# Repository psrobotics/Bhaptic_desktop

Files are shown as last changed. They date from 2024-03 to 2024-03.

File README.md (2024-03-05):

# Bhaptic_desktop

Bhaptic_desktop is a open-sorce, low-cost 3DOF desktop haptic device like [PHAToM haptic device](https://alliance.seas.upenn.edu/~medesign/wiki/uploads/Courses/Massie94-DSC-Phantom.pdf). It allows user to interact with the virtual while feeling the feedback force. It's an old project back in 2019.

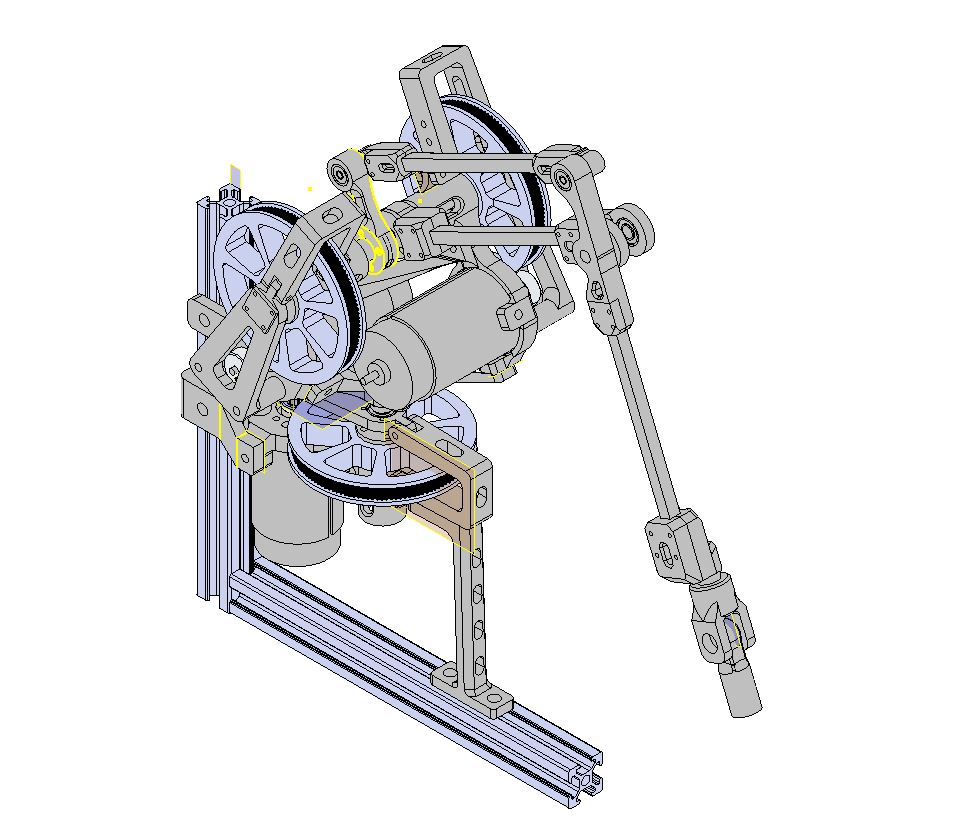
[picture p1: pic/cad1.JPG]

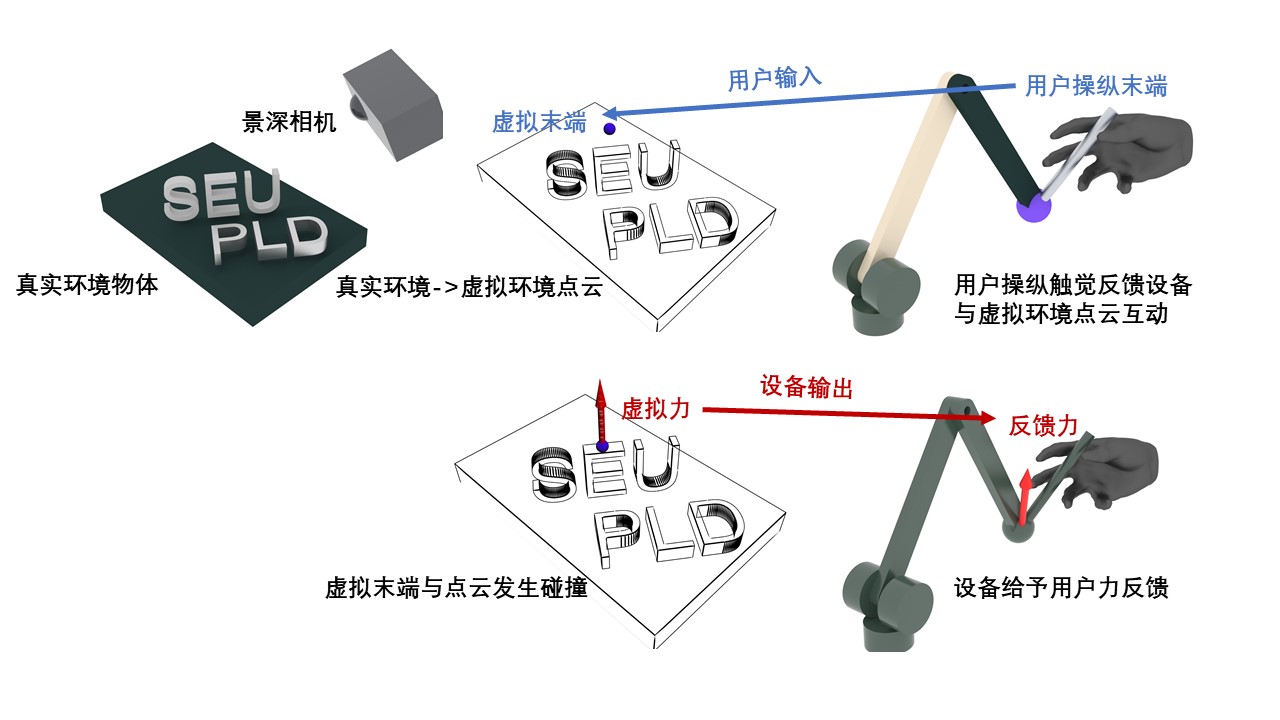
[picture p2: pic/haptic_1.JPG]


## Videos

Bhaptic action 3

## File Structure

* /hardware - CAD, STL exports, CAM file

* /electronic - Motor driver, Encoder reader

* /software - Arduino Firmware, PCL interface

## Pics

### [Motor](https://product.minebeamitsumi.com/en/product/category/rotary/brushmotor/dc/parts/M36N5E.html)


### Controller


### Docu
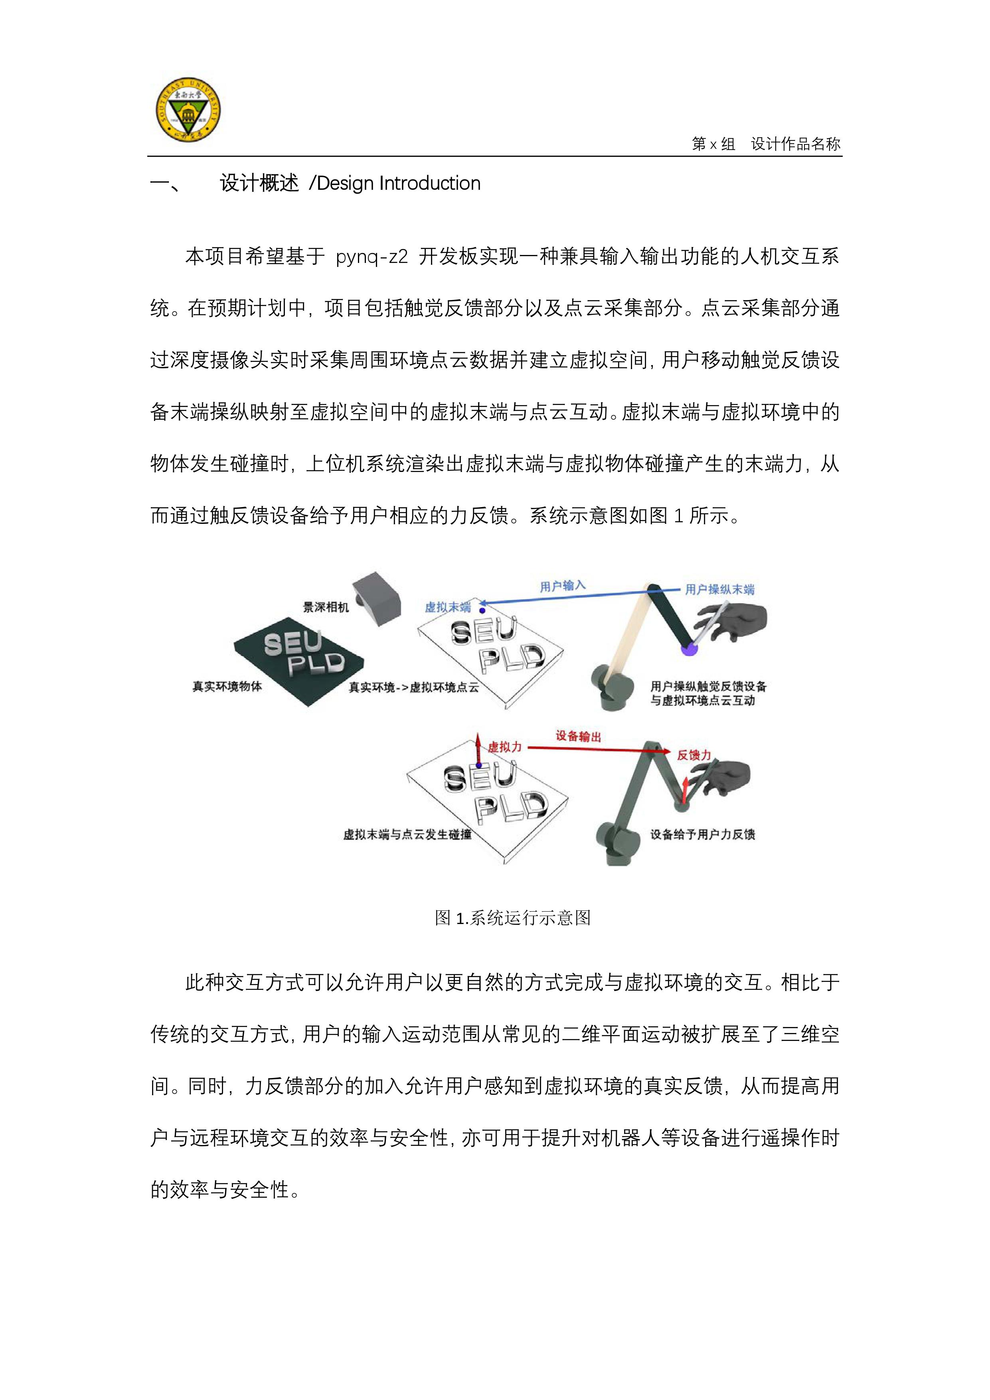
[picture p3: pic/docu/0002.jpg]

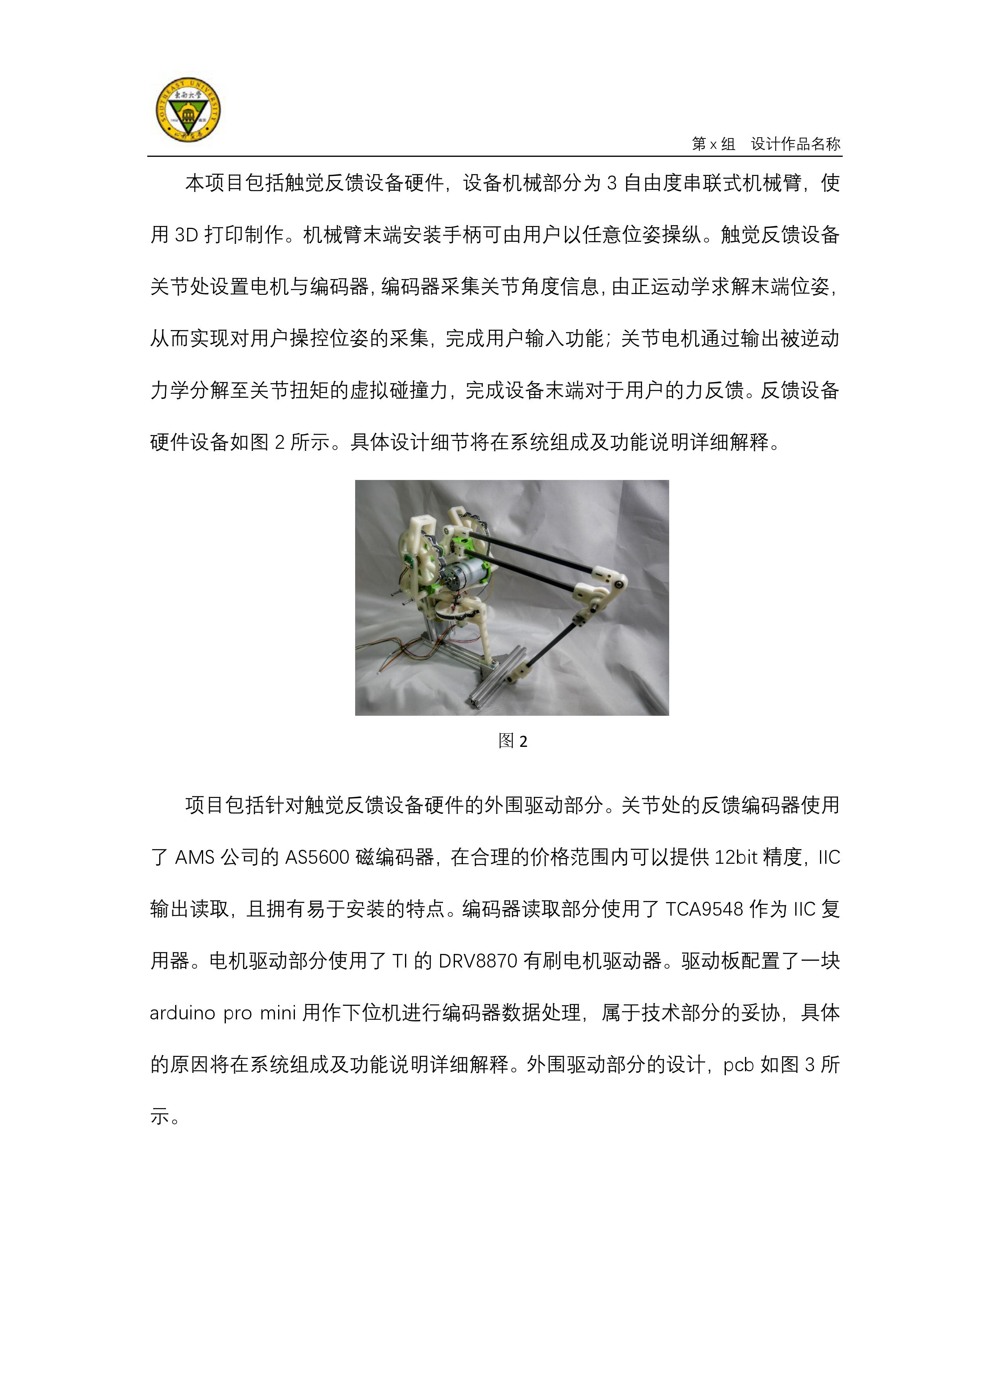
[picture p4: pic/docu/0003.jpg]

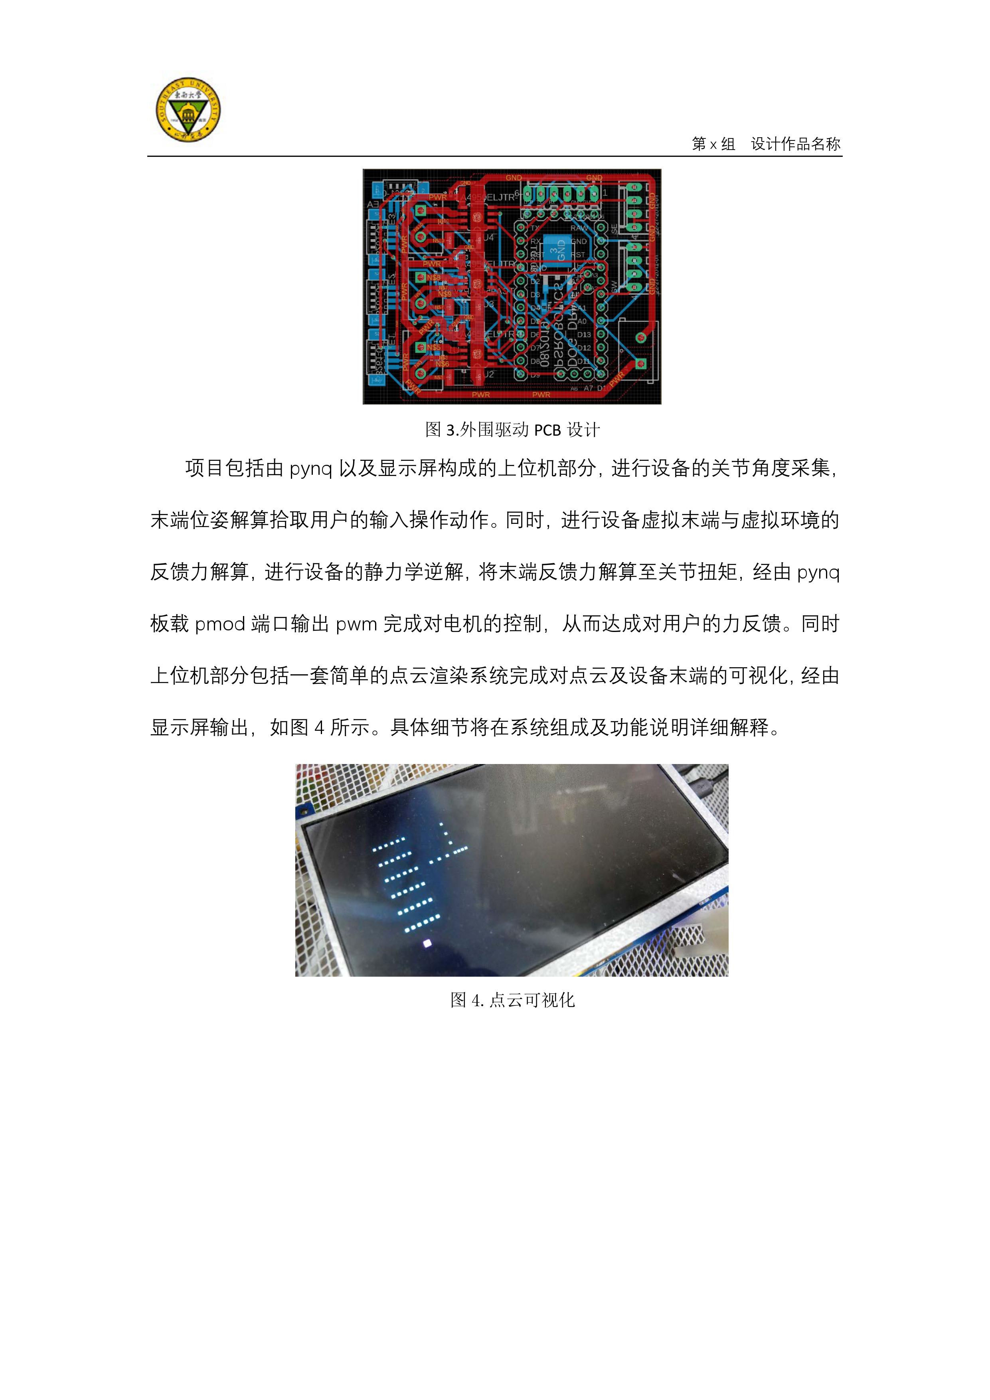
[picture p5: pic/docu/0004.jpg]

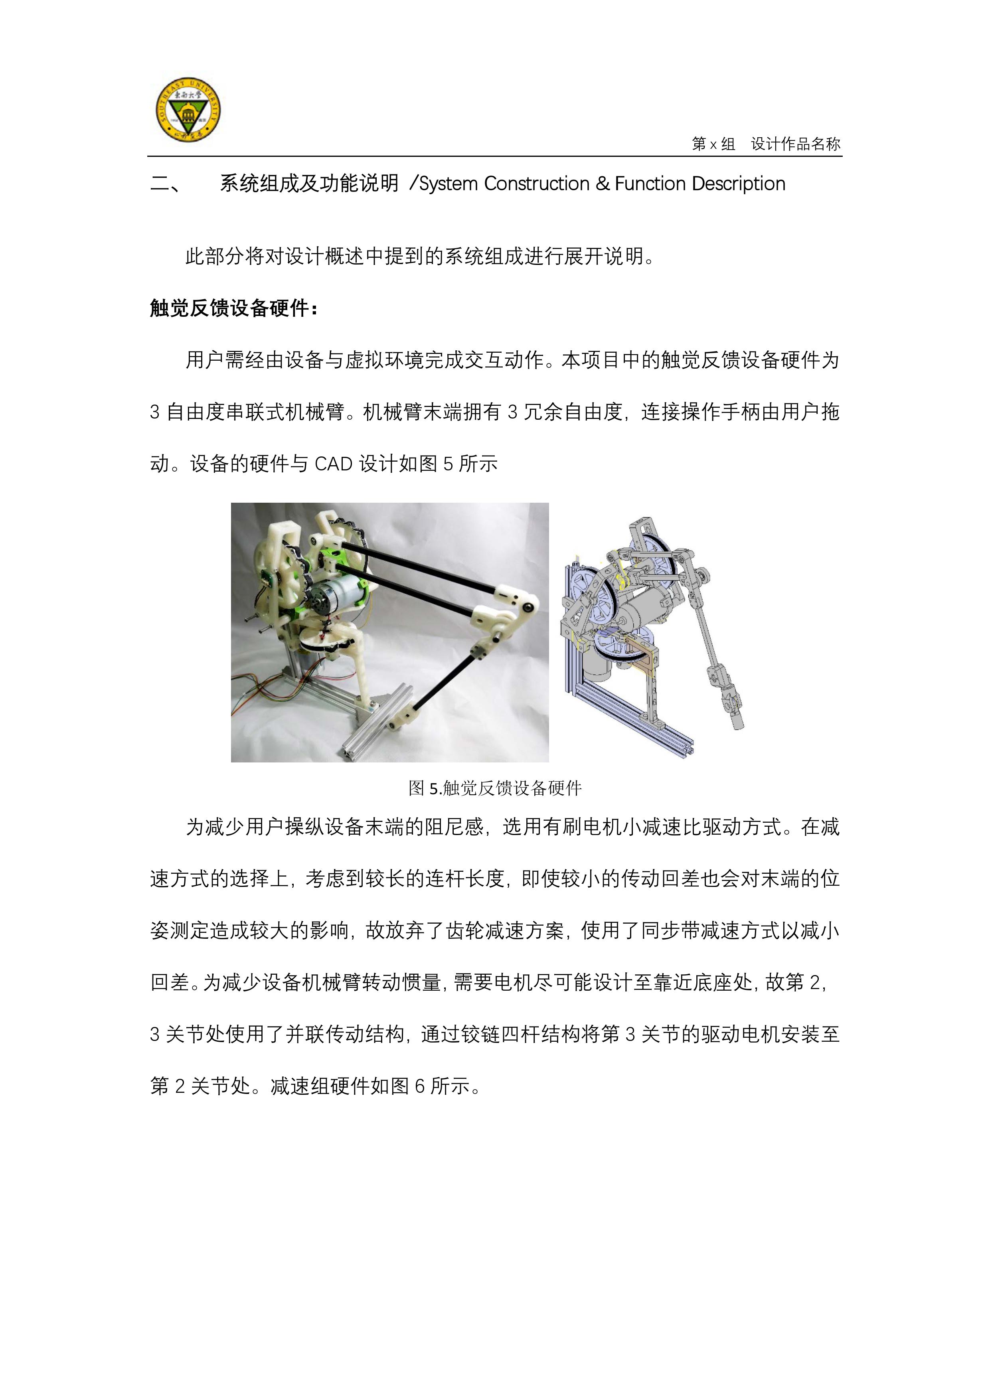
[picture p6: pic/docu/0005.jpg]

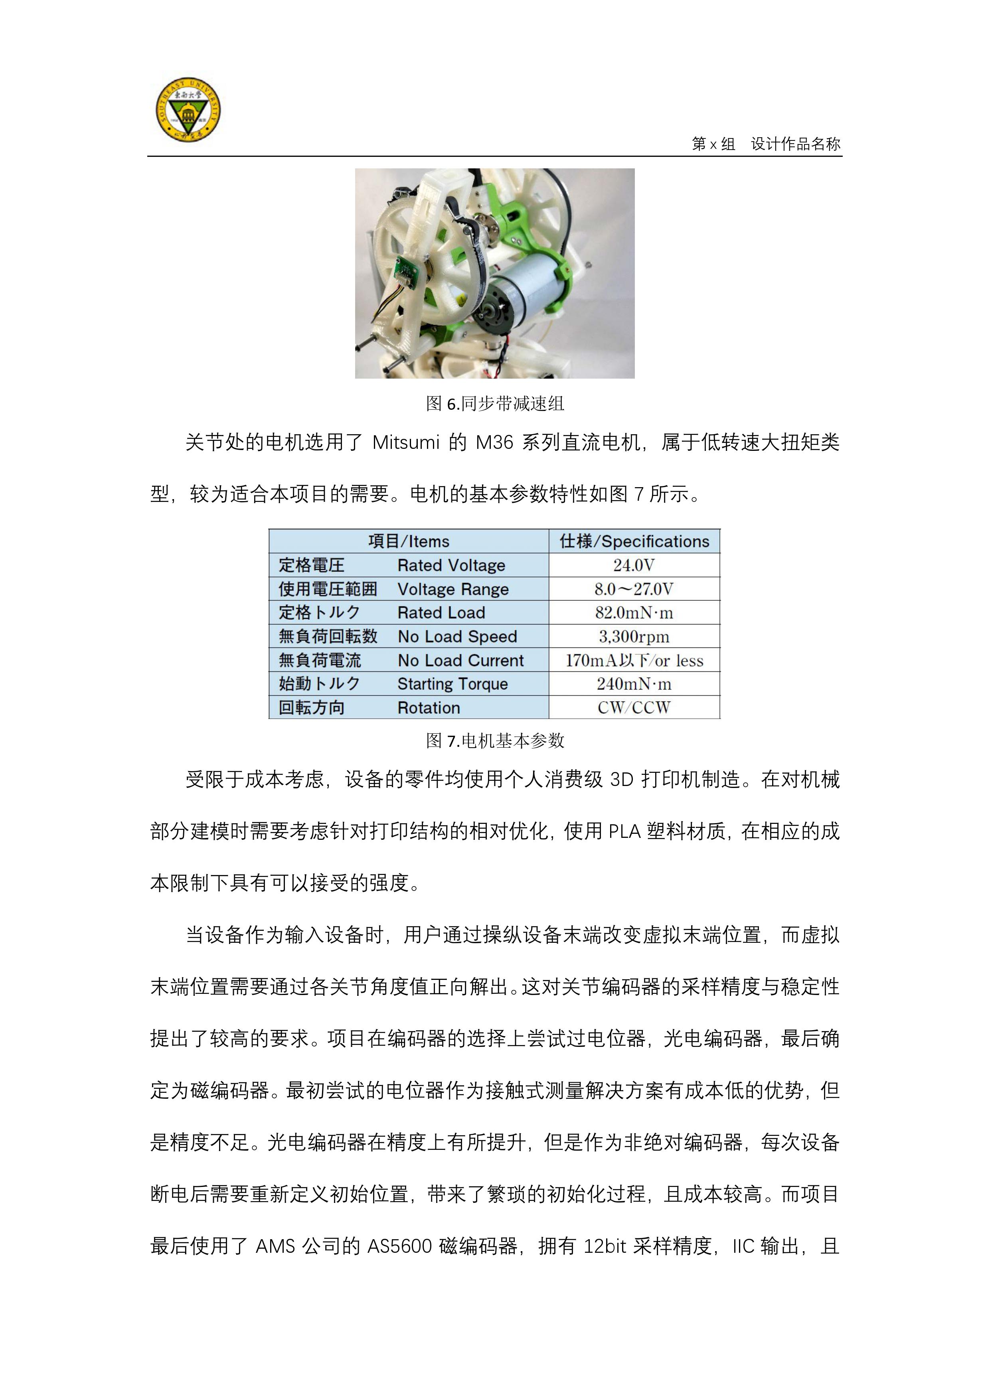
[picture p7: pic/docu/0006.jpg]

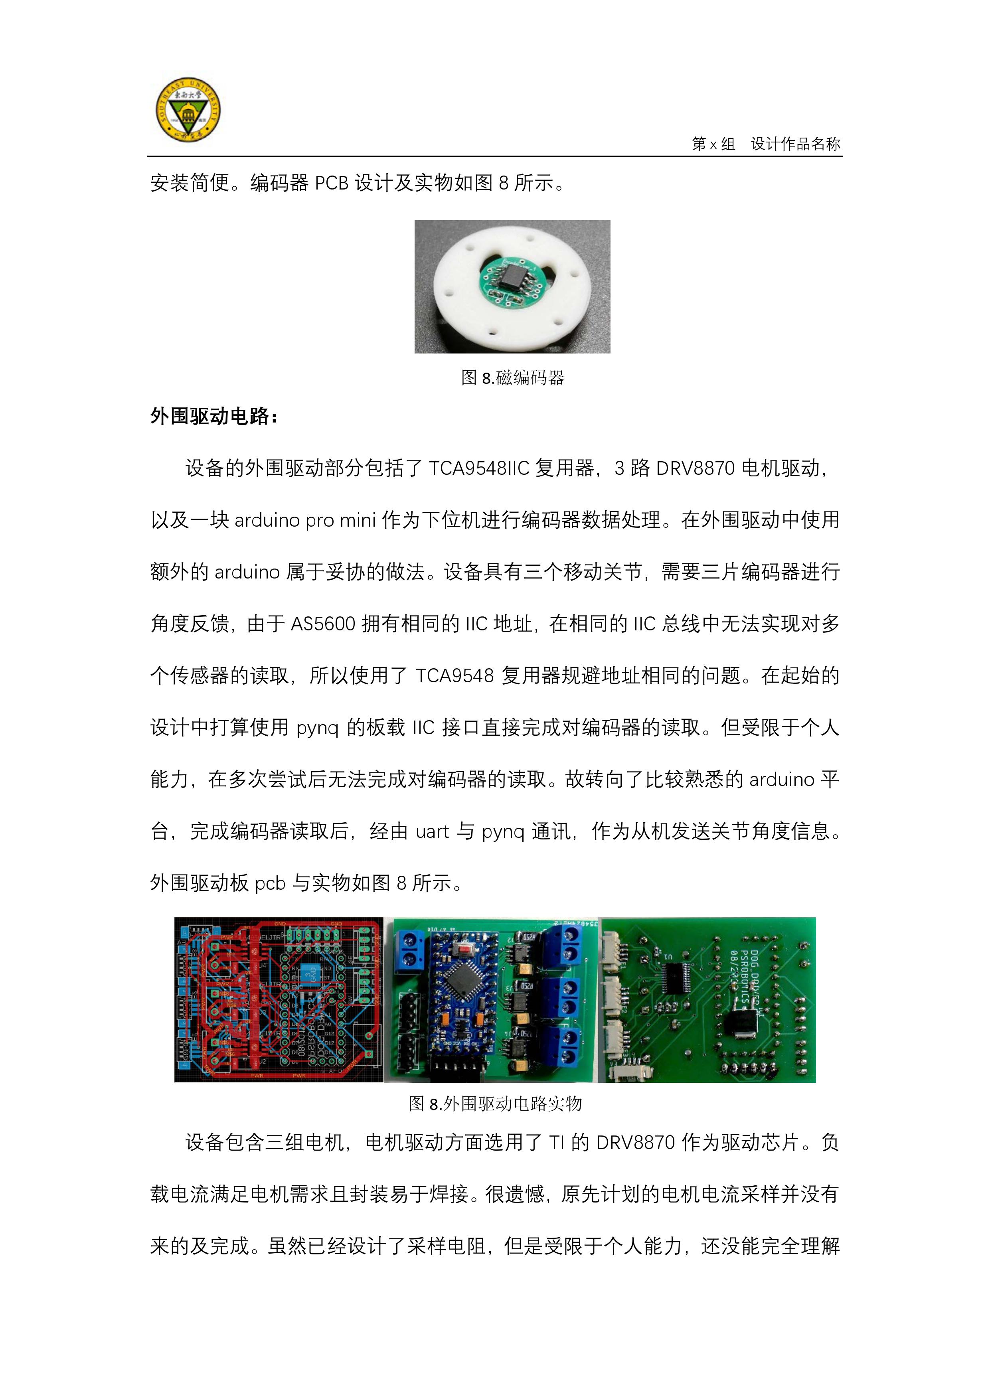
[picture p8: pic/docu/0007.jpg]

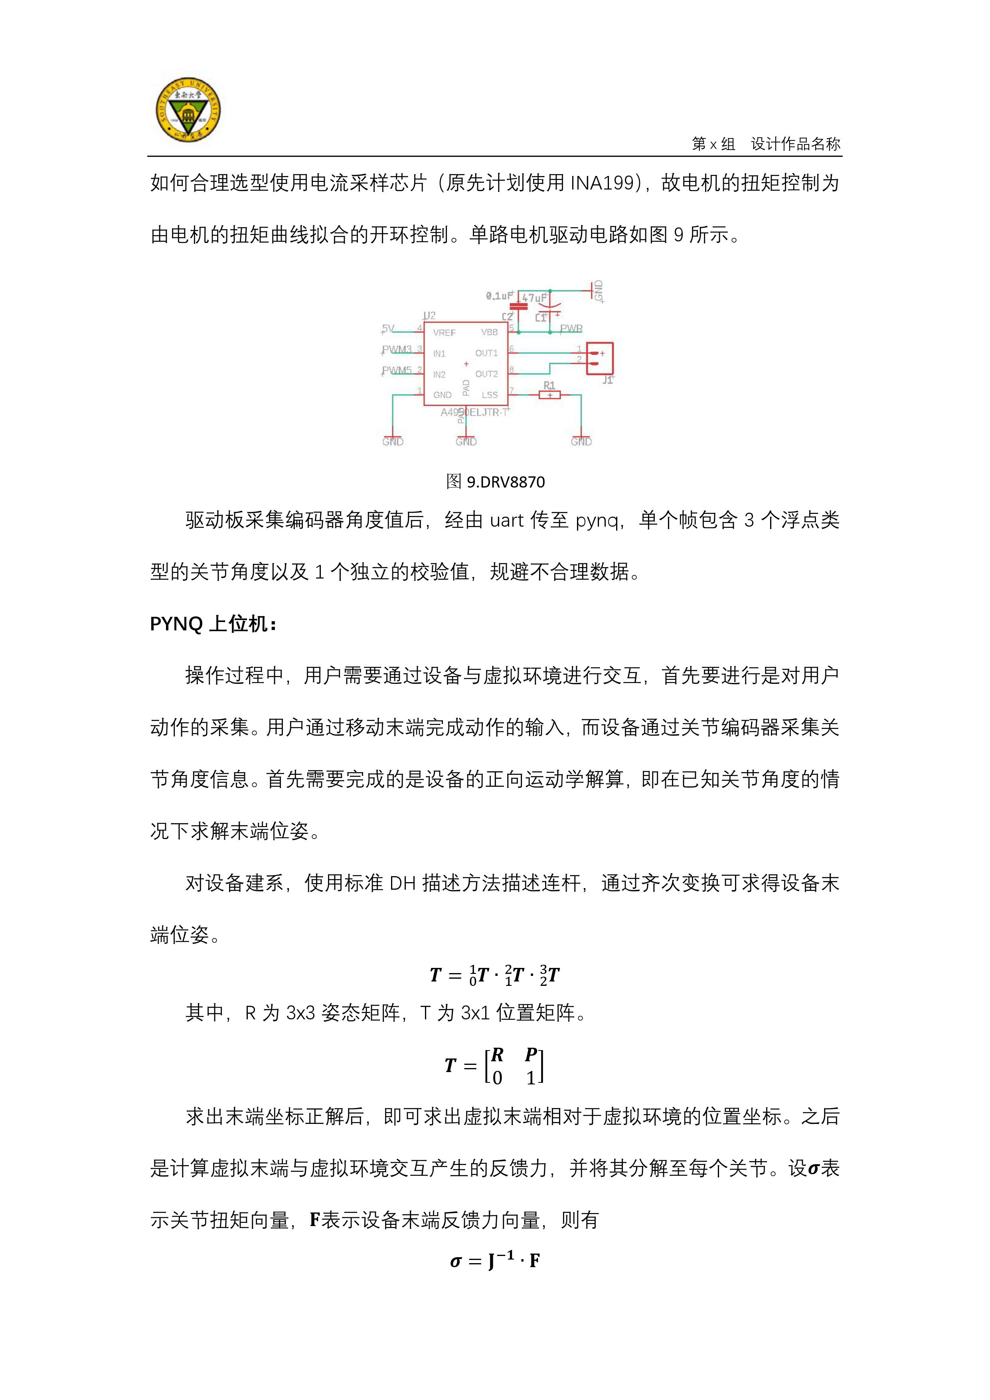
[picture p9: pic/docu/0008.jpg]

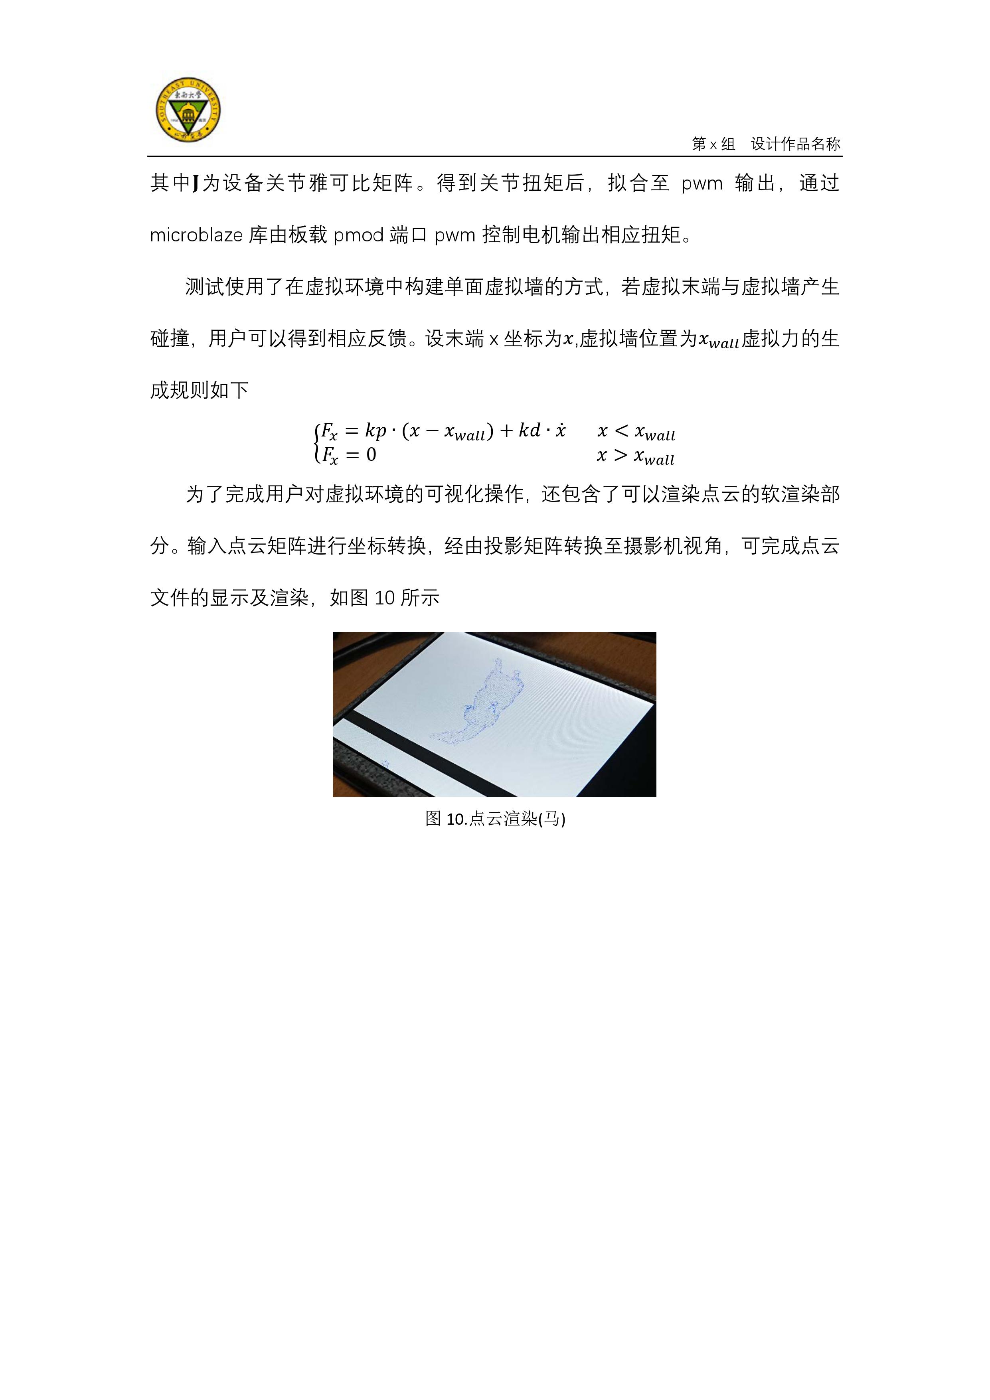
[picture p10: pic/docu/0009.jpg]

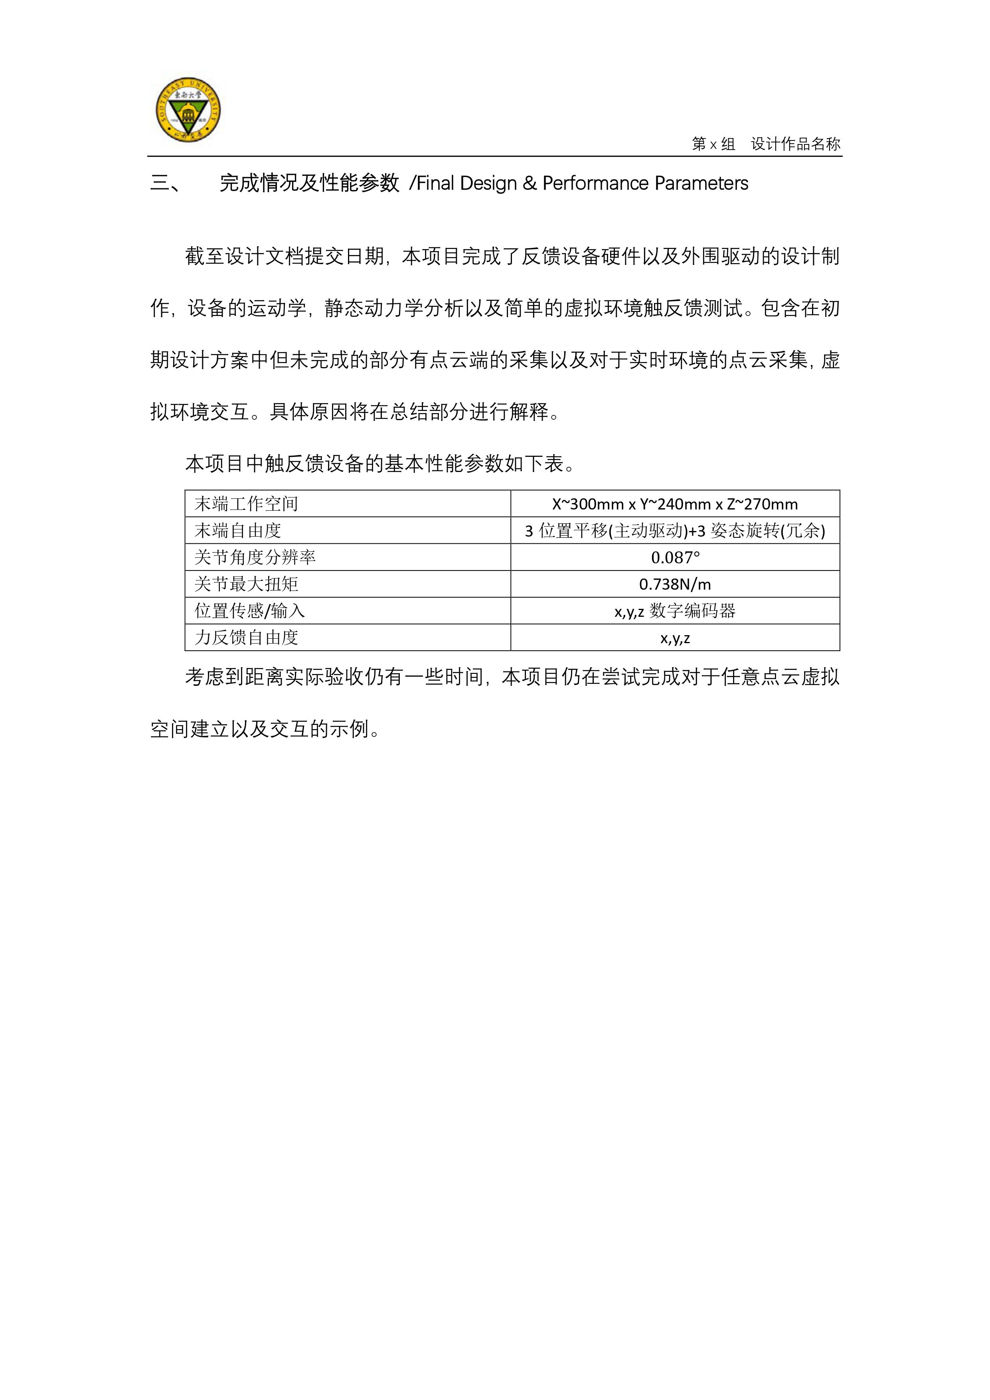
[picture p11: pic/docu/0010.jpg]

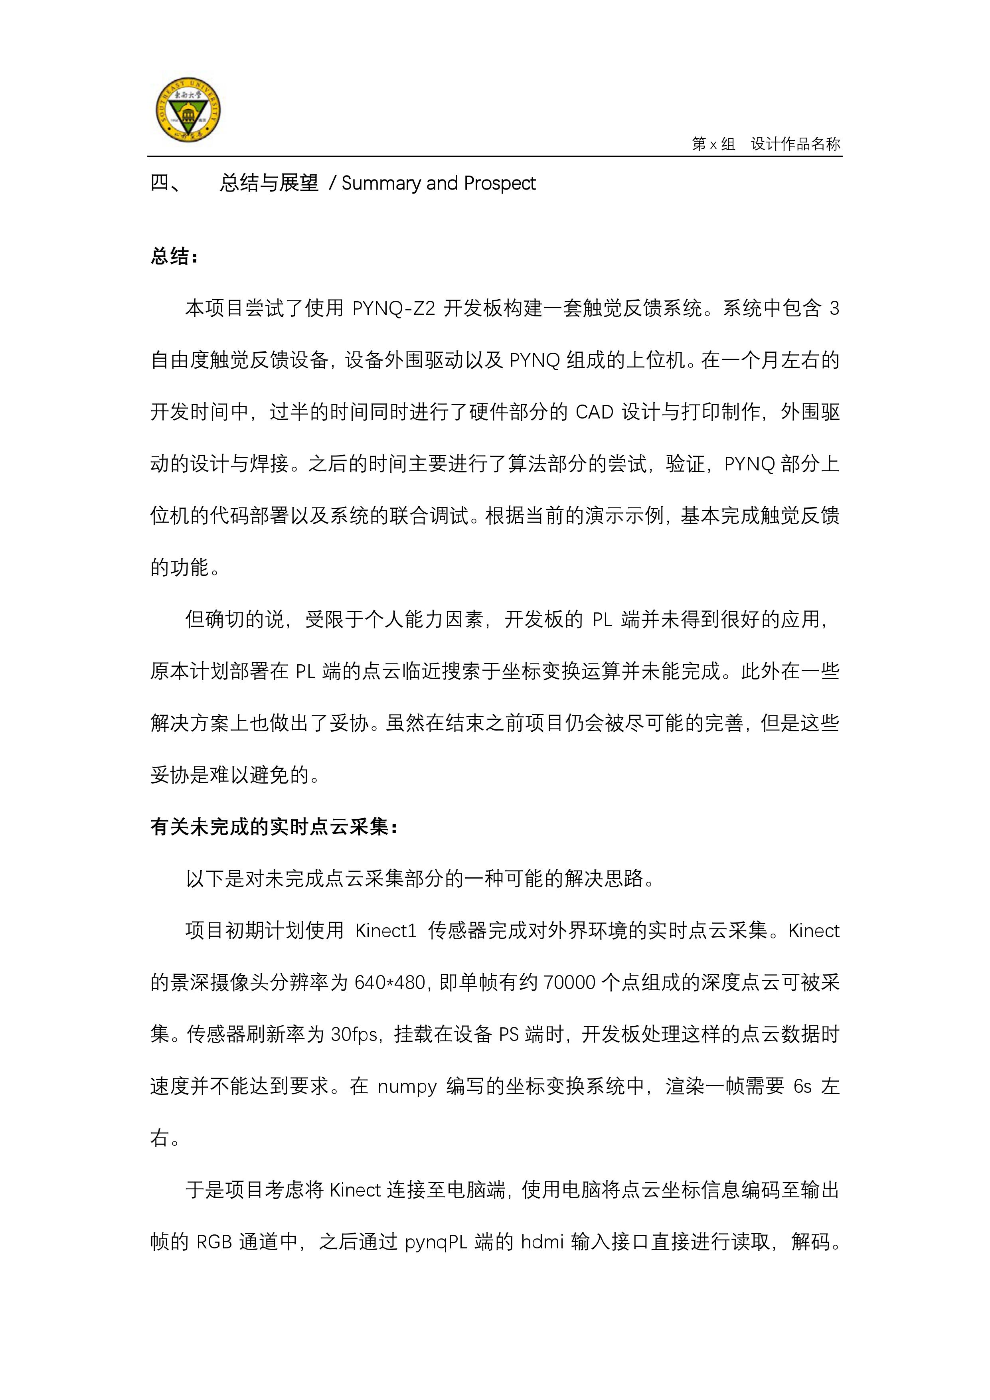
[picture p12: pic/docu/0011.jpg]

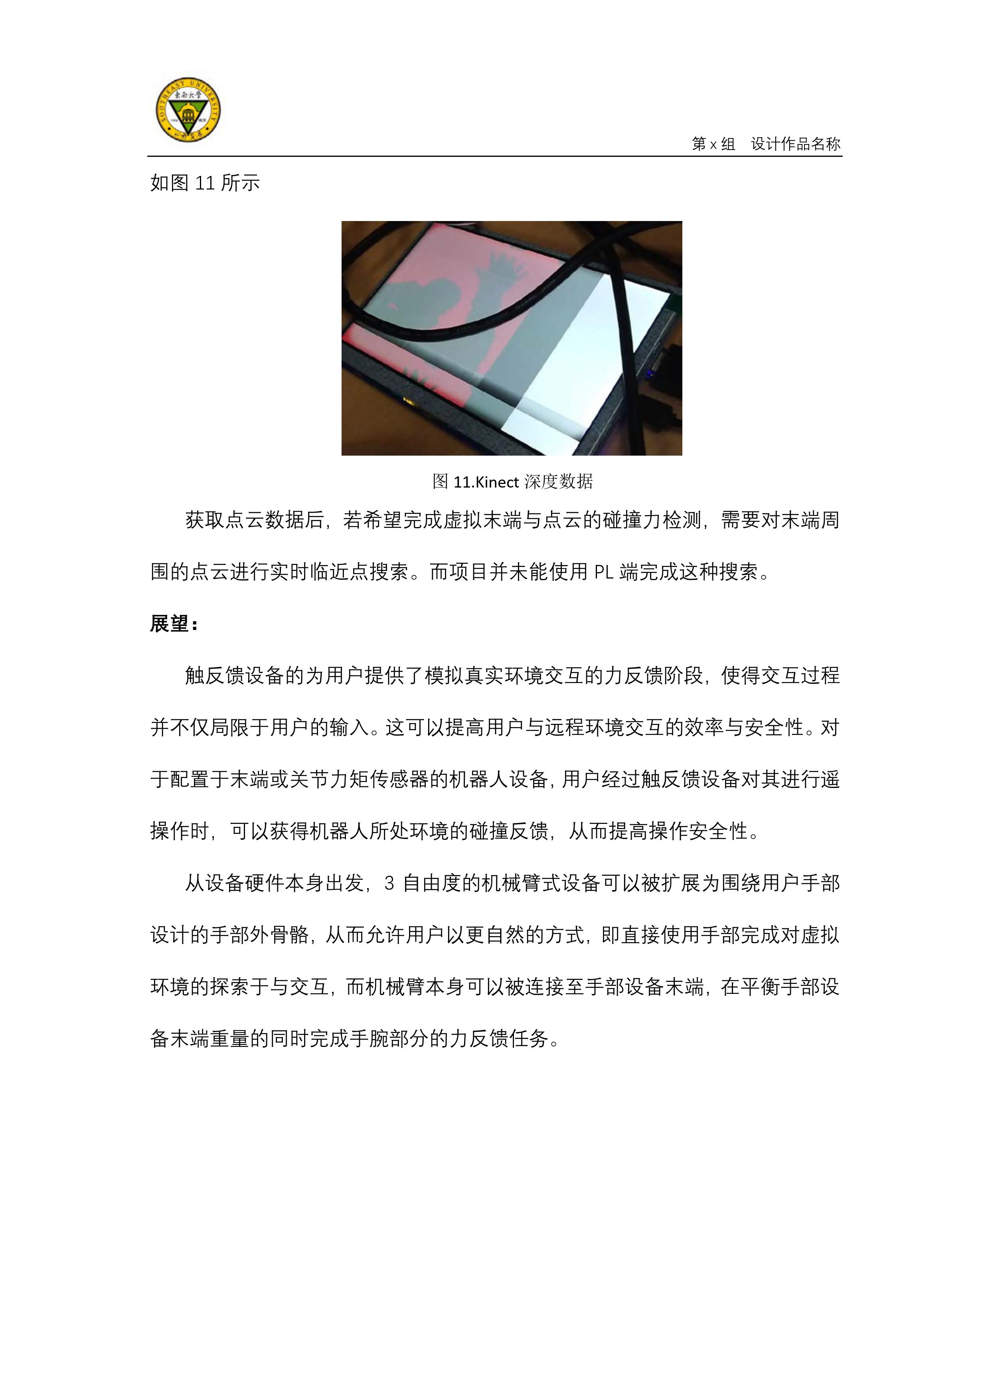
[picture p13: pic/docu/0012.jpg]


## License
MIT License

## Contact
* Shuang Peng, {shuangpe}@usc.edu

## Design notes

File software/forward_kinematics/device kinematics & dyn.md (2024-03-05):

# forward kinematics

```
result_mat_t = 
```



# jacobian matrix

```
J = 
```



```
J_1 = 
```



```
end_torque = 
```



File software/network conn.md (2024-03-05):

# network conn

first thing to do once startup:

sudo ifconfig eth0:1 192.168.2.99 netmask 255.255.255.0

sudo ifconfig eth0 192.168.137.19 netmask 255.255.255.0

```
export GIT_SSL_NO_VERIFY=1
```

sudo ./RedistMaker.Arm

 cp /home/xilinx/kinect/libfreenect/wrappers/python/freenect.c /home/xilinx/pynq/lib

 cp /home/xilinx/kinect/libfreenect/wrappers/python/frame_convert.py /home/xilinx/pynq/lib

 cp /home/xilinx/kinect/libfreenect/wrappers/python/frame_convert.py /home/xilinx/pynq/lib

 cp -r /home/xilinx/pwm_ar.ipynb /home/xilinx/jupyter_notebooks/pwm_test

 cp  -r /home/xilinx/kinect/libfreenect/wrappers/python /opt/python3.6/lib/python3.6/site-packages

sudo cp -r /home/xilinx/xyz/axis.xyz /home/xilinx/jupyter_notebooks/haptic_device_test

 cp  -r /home/xilinx/kinect/libfreenect/wrappers/python/freenect.c /opt/python3.6/lib/python3.6/site-packages

 cp  -r /home/xilinx/kinect/libfreenect/wrappers/python/freenect.pyx /opt/python3.6/lib/python3.6/site-packages

 cp  -r /home/xilinx/kinect/pykinect-python3.6/pykinect /opt/python3.6/lib/python3.6/site-packages

copy to the file lib file, otherwise unable to open

sudo apt-get install python3-pip

 cp /usr/local/lib/python2.7/dist-packages/freenect-0.0.0.egg-info /usr/local/lib/python3.5/dist-packages

 cp /usr/local/lib/python2.7/dist-packages/freenect.so /usr/local/lib/python3.5/dist-packages

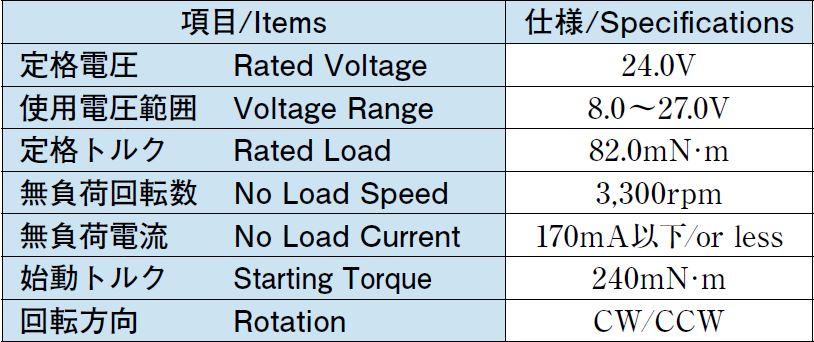
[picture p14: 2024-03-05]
pic/motor_spec.JPG

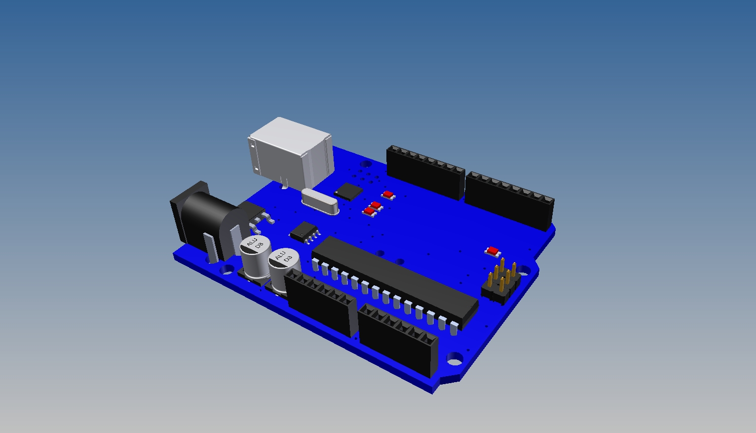
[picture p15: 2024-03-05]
hardware/arduino-uno.snapshot.3/Renderings/arduino uno.jpg

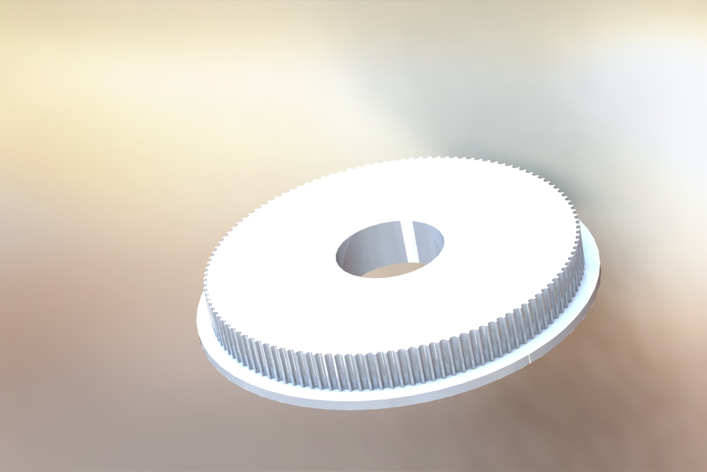
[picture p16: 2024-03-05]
hardware/gt2-pulley-120-tooth-1.snapshot.1/120teeth gt2 pulley picture.JPG

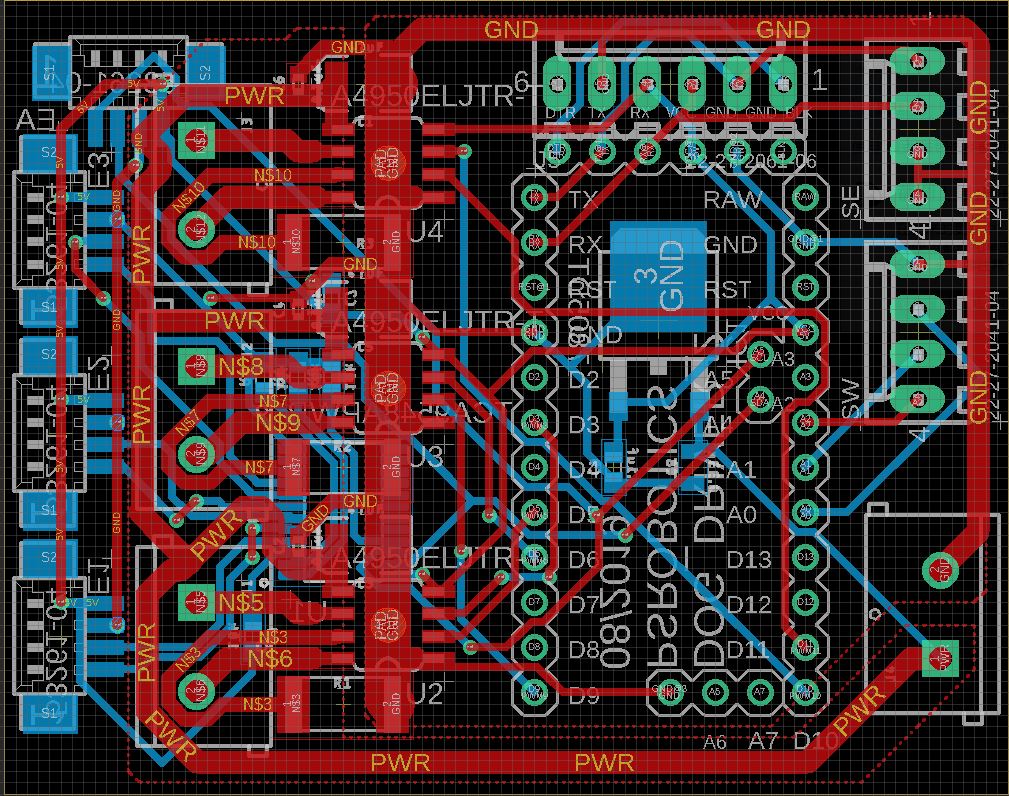
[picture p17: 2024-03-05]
pic/ele_pcb.jpg

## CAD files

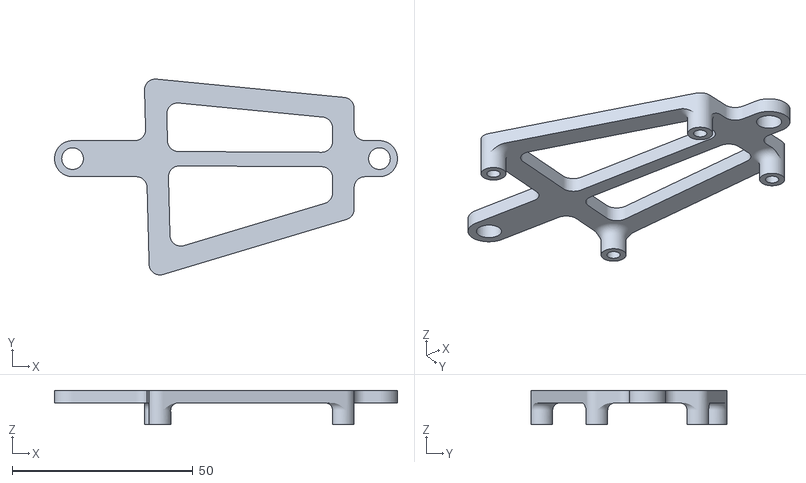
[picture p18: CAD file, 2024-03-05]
hardware/arduino-uno.snapshot.3/uno_holder.stl
95.0 x 54.3 x 9.50

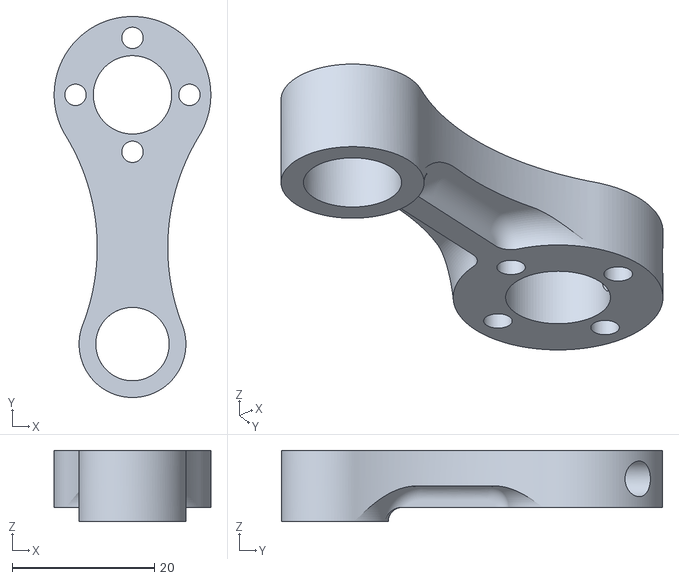
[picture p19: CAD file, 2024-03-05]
hardware/export_20190921/arm_linkage_1_mod.stl
22.0 x 53.5 x 10.0

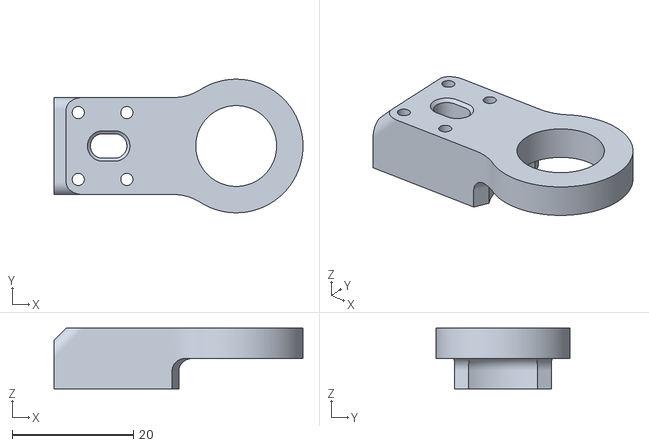
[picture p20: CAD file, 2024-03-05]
hardware/export_20191015/armtip_3.stl
41.0 x 22.0 x 10.0

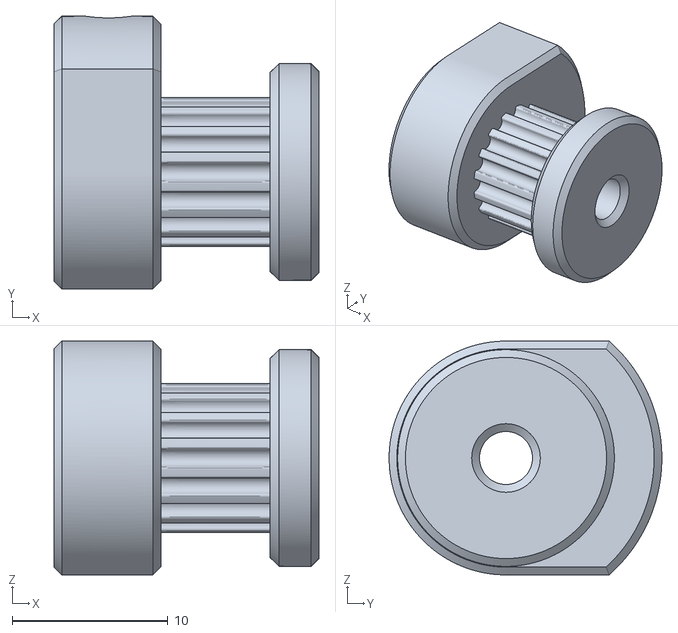
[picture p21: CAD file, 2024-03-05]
hardware/export_20191016/GT2_16T_mod.stl
17.0 x 17.5 x 15.0

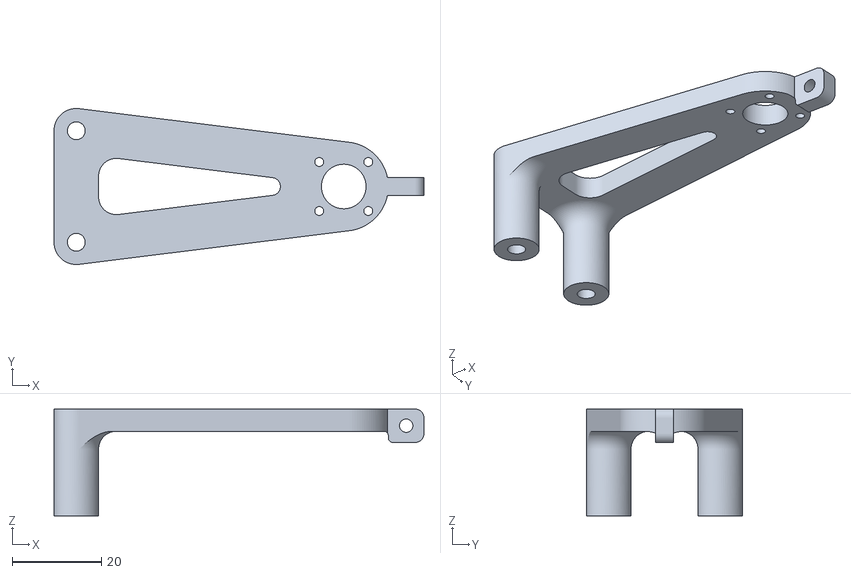
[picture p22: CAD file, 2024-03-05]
hardware/export_20191017/sensor_holder_1_mod.stl
83.0 x 35.0 x 24.0

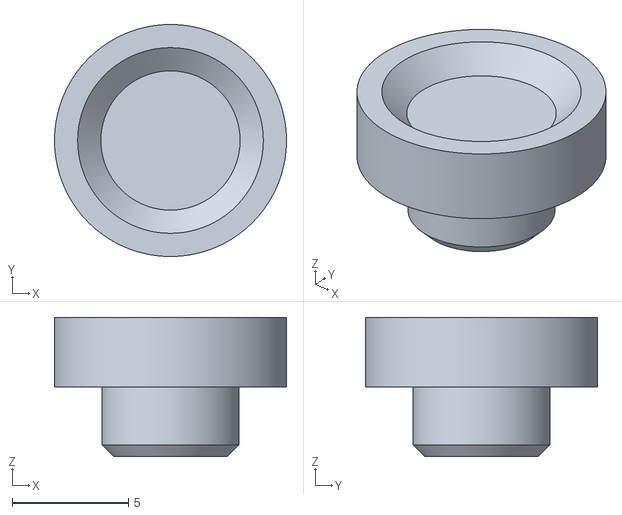
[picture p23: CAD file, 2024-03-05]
hardware/export_20191018/encoder_ma_holder.stl
10.0 x 10.0 x 6.00

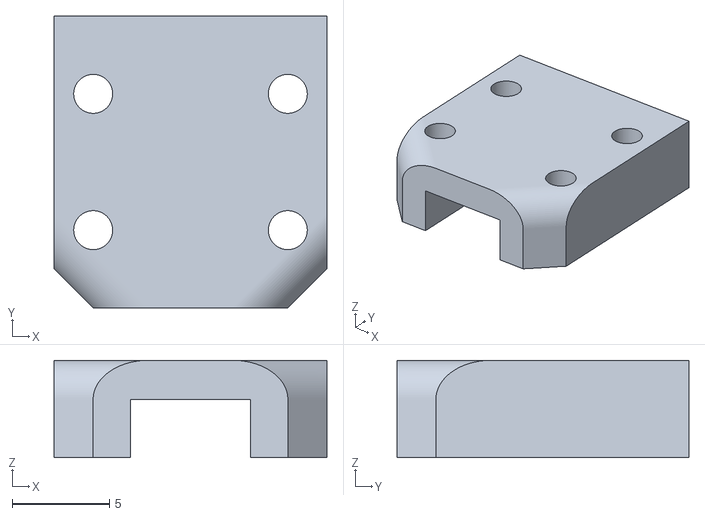
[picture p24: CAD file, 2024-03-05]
hardware/export_20191022/sub_arm_2_mod.stl
14.0 x 15.0 x 5.00

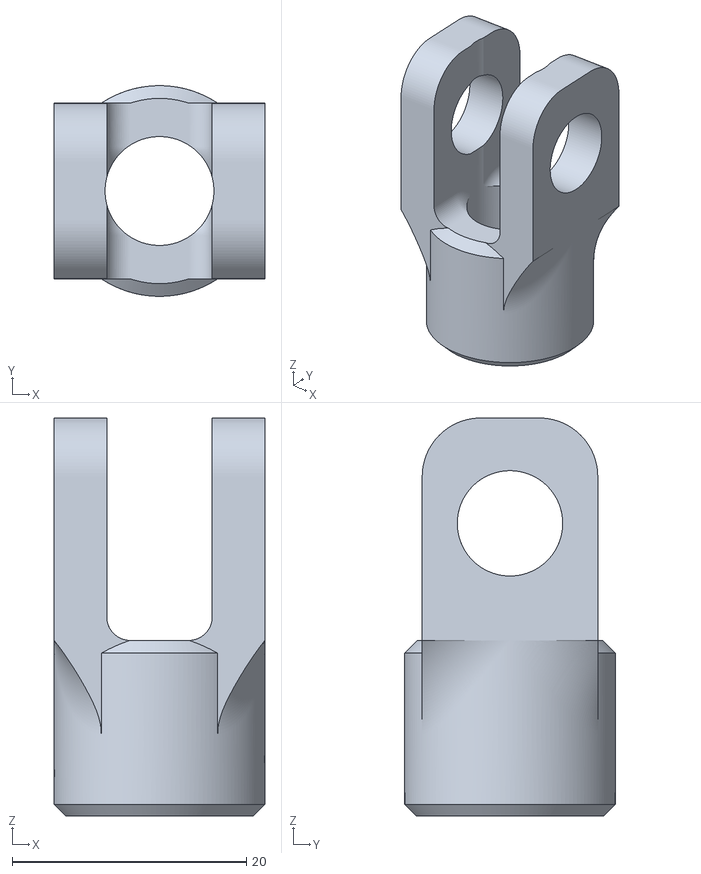
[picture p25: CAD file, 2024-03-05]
hardware/export_20191028/arm_tip_3.stl
18.0 x 18.0 x 34.0

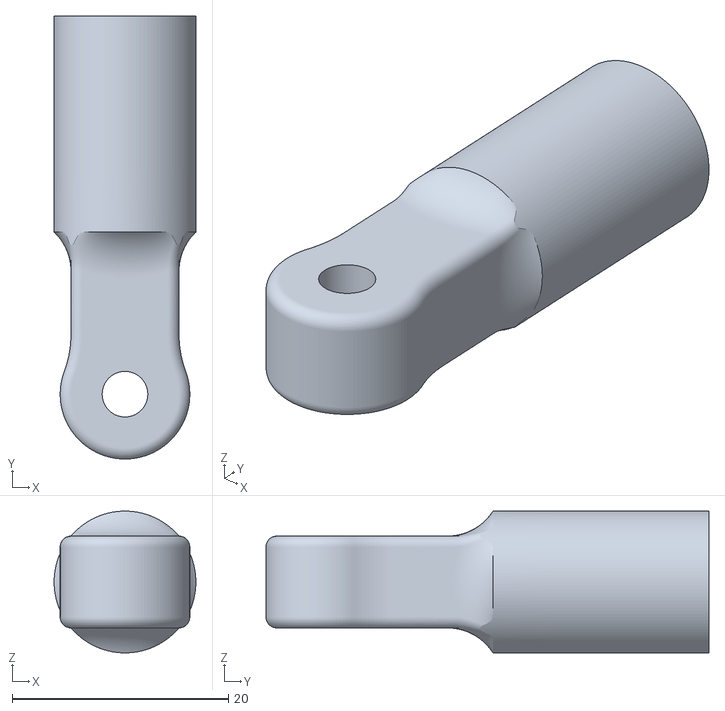
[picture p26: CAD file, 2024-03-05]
hardware/export_20191101/arm_tip_4.stl
13.1 x 41.0 x 13.1

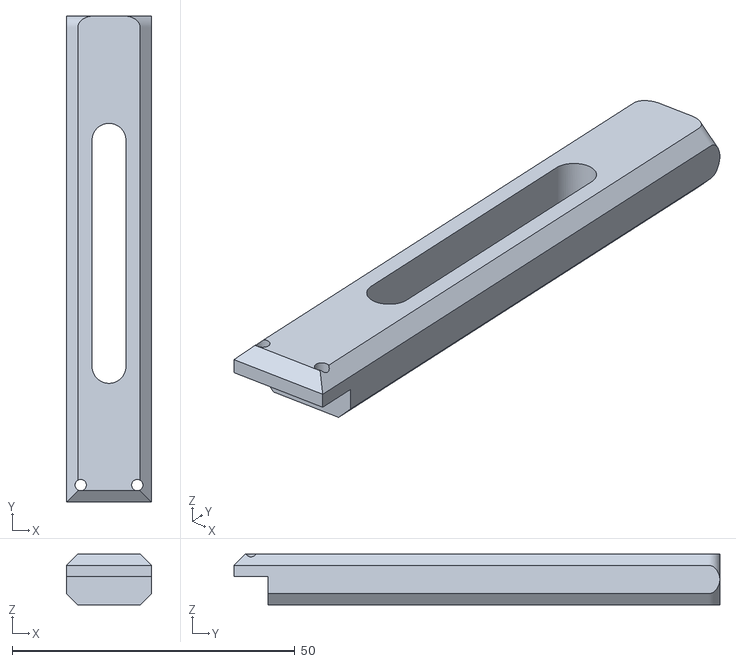
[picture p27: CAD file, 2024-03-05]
hardware/export_20191105/pen_2.stl
15.0 x 86.0 x 9.00

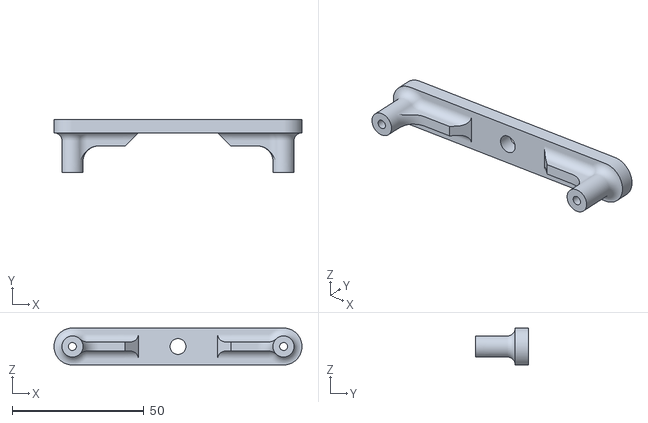
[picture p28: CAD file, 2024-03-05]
hardware/export_20191107/board_holder.stl
94.0 x 20.0 x 14.0

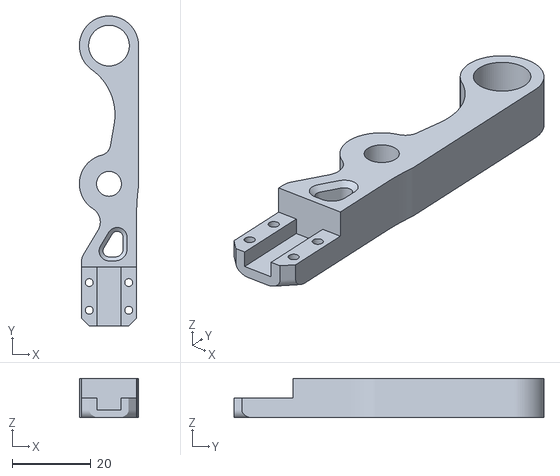
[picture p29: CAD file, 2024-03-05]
hardware/export_20191220/sub_arm_1_mod.stl
15.0 x 78.5 x 10.0

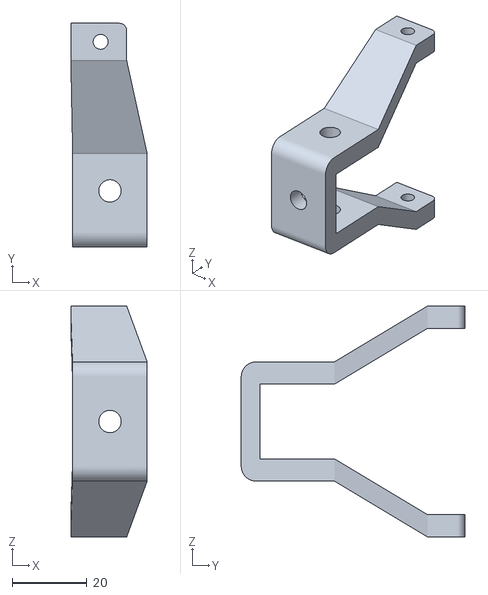
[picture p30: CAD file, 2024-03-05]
hardware/export_20191223/2020_fixer2.stl
20.5 x 60.0 x 62.0

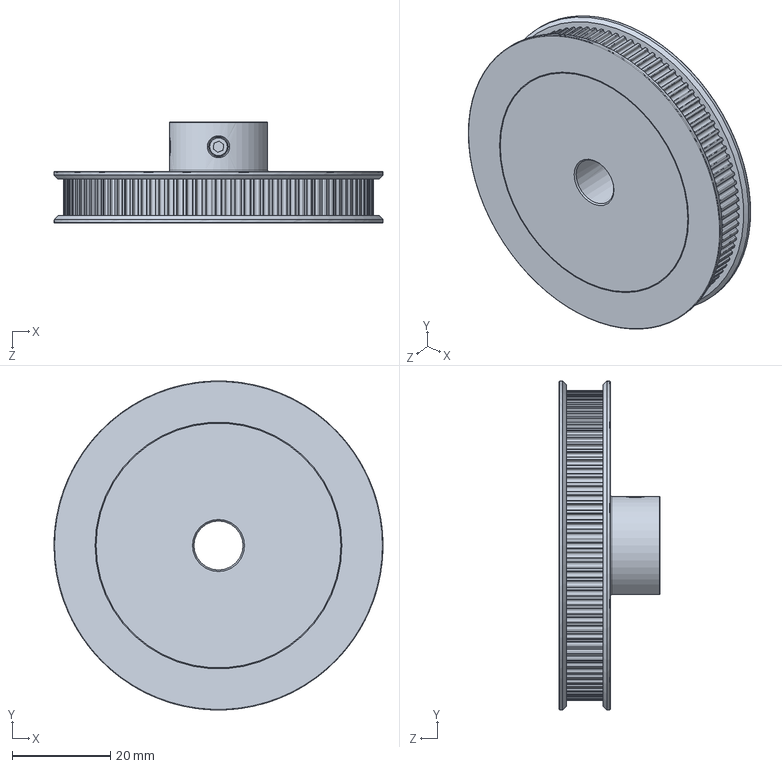
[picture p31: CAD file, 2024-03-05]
hardware/gt2-100-teeth-bore-10mm-belt-6mm-1.snapshot.1/GT2_100T_10_6.SLDPRT
67.0 x 67.0 x 20.6 mm

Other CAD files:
hardware/gt2-pulley-120-tooth-1.snapshot.1/120teeth gt2 pulley.SLDPRT
hardware/export_20190921/arm_linkage_2_mod.stl
hardware/export_20191015/arm_frame_3.stl
hardware/export_20191016/GT2_16T_mod1.stl
hardware/2020.ipt
hardware/2020_fixer2.ipt
hardware/2020_fixer_1.ipt
hardware/2200_support_3.ipt
hardware/4_20.ipt
hardware/GT2_16T.ipt
hardware/OldVersions/2020.0002.ipt
hardware/OldVersions/2020_fixer2.0002.ipt
hardware/OldVersions/2020_fixer_1.0004.ipt
hardware/OldVersions/2200_support_3.0005.ipt
hardware/OldVersions/GT2_16T.0006.ipt
hardware/OldVersions/arm_frame_2.0003.ipt
hardware/OldVersions/arm_frame_3.0004.ipt
hardware/OldVersions/arm_linkage_1.0002.ipt
hardware/OldVersions/arm_linkage_1.0005.ipt
hardware/OldVersions/arm_linkage_2.0002.ipt
hardware/OldVersions/arm_linkage_2.0004.ipt
hardware/OldVersions/arm_linkage_2.0005.ipt
hardware/OldVersions/arm_linkage_3.0004.ipt
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

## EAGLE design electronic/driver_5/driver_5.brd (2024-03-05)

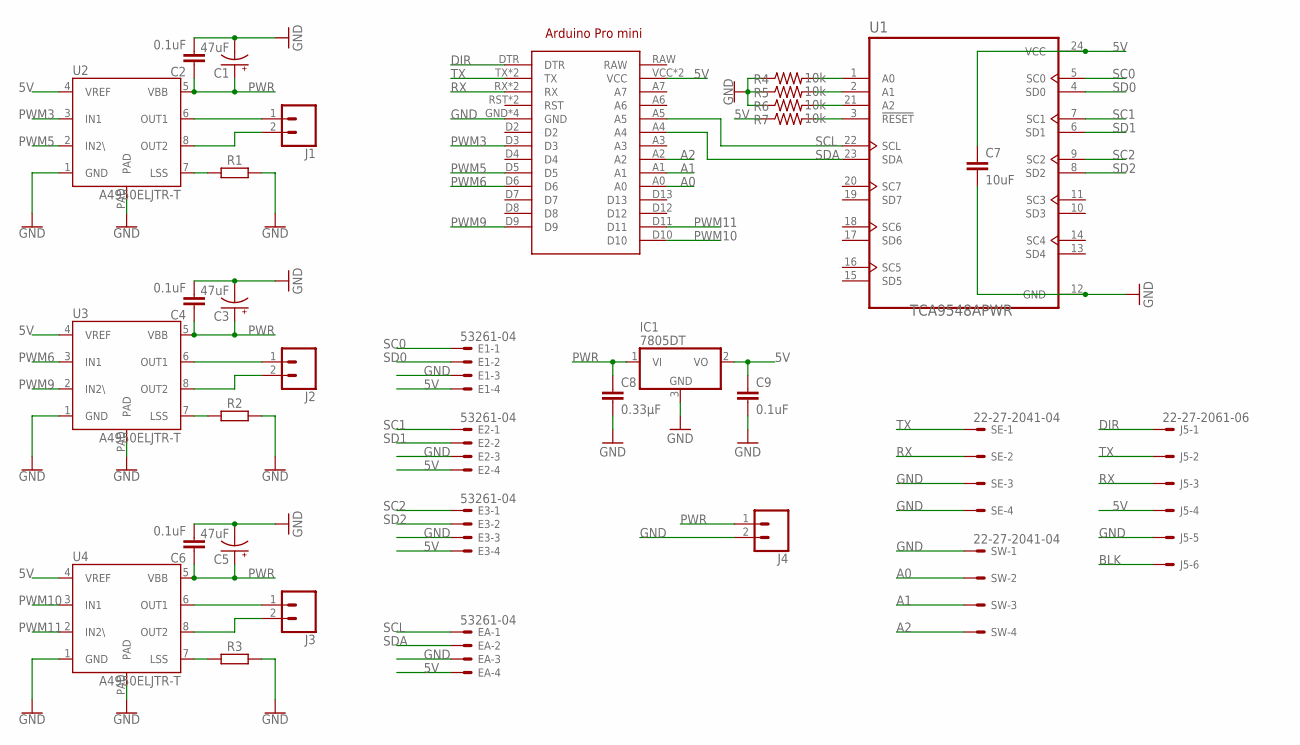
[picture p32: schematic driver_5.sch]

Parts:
ARDUINO1: ARDUINO_PRO_MINI
C1, C3, C5: 47uF; EIA3528
C2, C4, C6: 0.1uF; 0402
C7: 10uF; 0603
C8: 0.33µF; 0805
C9: 0.1uF; 0603
E1, E2, E3: 53261-04
EA: 53261-04
IC1: 7805DT; TO252
J1, J2, J3, J4: CONN_025MM; SCREWTERMINAL-5MM-2
J5: 22-27-2061-06; 6410-06
R1, R2, R3: 0.22; R2512
R4, R5, R6, R7: 10k; 0603
SE: 22-27-2041-04; 6410-04
SW: 22-27-2041-04; 6410-04
U1: TCA9548APWR; SOP65P640X120-24N
U2, U3, U4: A4950ELJTR-T; SOIC8TP

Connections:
5V: ARDUINO1.VCC, ARDUINO1.VCC@1 (VCC), C7.1, C9.1, E1.4, E2.4, E3.4, EA.4, IC1.2 (VO), J5.4, R7.1, U1.24 (VCC), U2.4 (VREF), U3.4 (VREF), U4.4 (VREF)
A0: ARDUINO1.A0, SW.2
A1: ARDUINO1.A1, SW.3
A2: ARDUINO1.A2, SW.4
BLK: J5.6
DIR: ARDUINO1.DTR, J5.1
GND: ARDUINO1.GND, ARDUINO1.GND@1 (GND), ARDUINO1.GND@2 (GND), ARDUINO1.GND@3 (GND), C1.C (-), C2.2, C3.C (-), C4.2, C5.C (-), C6.2, C7.2, C8.2, C9.2, E1.3, E2.3, E3.3, EA.3, IC1.3 (GND), J4.2, J5.5, R1.2, R2.2, R3.2, R4.1, R5.1, R6.1, SE.3, SE.4, SW.1, U1.12 (GND), U2.1 (GND), U2.PAD, U3.1 (GND), U3.PAD, U4.1 (GND), U4.PAD
unnamed: R1.1, U2.7 (LSS)
unnamed: R4.2, U1.1 (A0)
unnamed: J1.1, U2.6 (OUT1)
unnamed: J1.2, U2.8 (OUT2)
unnamed: R2.1, U3.7 (LSS)
unnamed: J2.1, U3.6 (OUT1)
unnamed: J2.2, U3.8 (OUT2)
unnamed: R3.1, U4.7 (LSS)
unnamed: J3.1, U4.6 (OUT1)
unnamed: J3.2, U4.8 (OUT2)
unnamed: R5.2, U1.2 (A1)
unnamed: R6.2, U1.21 (A2)
unnamed: R7.2, U1.3 (!RESET)
PWM3: ARDUINO1.D3, U2.3 (IN1)
PWM5: ARDUINO1.D5, U2.2 (IN2\)
PWM6: ARDUINO1.D6, U3.3 (IN1)
PWM9: ARDUINO1.D9, U3.2 (IN2\)
PWM10: ARDUINO1.D10, U4.3 (IN1)
PWM11: ARDUINO1.D11, U4.2 (IN2\)
PWR: C1.A (+), C2.1, C3.A (+), C4.1, C5.A (+), C6.1, C8.1, IC1.1 (VI), J4.1, U2.5 (VBB), U3.5 (VBB), U4.5 (VBB)
RX: ARDUINO1.RX, ARDUINO1.RX@1 (RX), J5.3, SE.2
SC0: E1.1, U1.5 (SC0)
SC1: E2.1, U1.7 (SC1)
SC2: E3.1, U1.9 (SC2)
SCL: ARDUINO1.A5, EA.1, U1.22 (SCL)
SD0: E1.2, U1.4 (SD0)
SD1: E2.2, U1.6 (SD1)
SD2: E3.2, U1.8 (SD2)
SDA: ARDUINO1.A4, EA.2, U1.23 (SDA)
TX: ARDUINO1.TX, ARDUINO1.TX@1 (TX), J5.2, SE.1

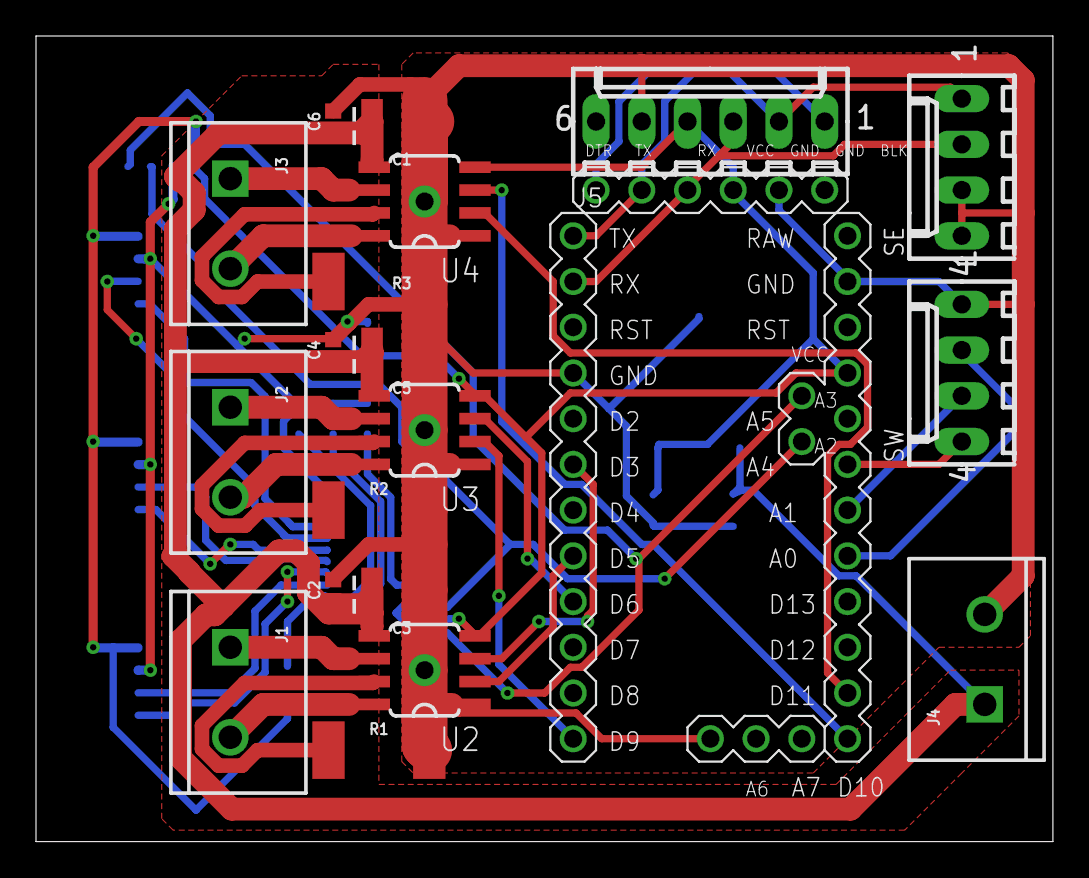
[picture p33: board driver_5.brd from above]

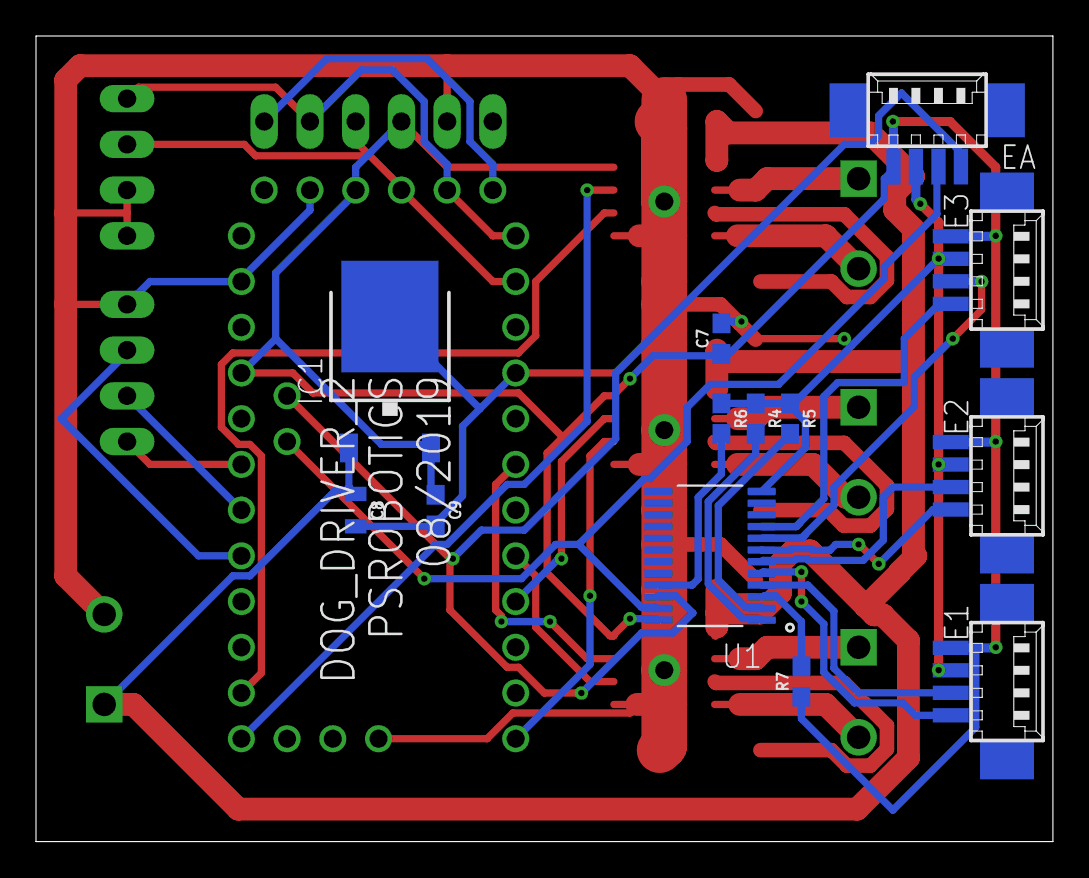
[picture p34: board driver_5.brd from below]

Board: 2 copper layers, 56.5 x 44.8 mm, 33 parts (13 on the bottom side), 36 nets.

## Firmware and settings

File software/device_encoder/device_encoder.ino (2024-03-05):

#include <Wire.h>
#include "TCA9548A.h"
#include "AS5600.h"
#include <SoftwareSerial.h>

SoftwareSerial serial1(7, 8); // RX, TX

TCA9548A device1;
AS5600 sensor;

const int receive_pack_len=5;

class encoder
{
  public:
    int EncoderId;
    int ReadRaw;
    double AngleRaw;
    double AnglePro;
    int dir;
    int offset;

    encoder(int id);
    int GetRaw();
    double GetAngleraw();
    double GetAnglepro();
    void SetOffset(double in);
    void SetDir(int in);
    friend void PrintData();
};
encoder::encoder(int id)
{
  EncoderId = id;
  dir = 1;
  offset = 0;
}
int encoder::GetRaw()
{
  device1.set_port(EncoderId);
  ReadRaw = sensor.getAngle();
  return ReadRaw;
}
double encoder::GetAngleraw()
{
  device1.set_port(EncoderId);
  ReadRaw = sensor.getAngle();
  AngleRaw = (ReadRaw / 4096.0) * 360.0;
  return AngleRaw;
}
double encoder::GetAnglepro()
{
  device1.set_port(EncoderId);
  ReadRaw = sensor.getAngle();
  AngleRaw = (ReadRaw / 4096.0) * 360.0;
  AnglePro = dir * AngleRaw + offset;
  return AnglePro;
}
void encoder::SetOffset(double in)
{
  offset = in;
}
void encoder::SetDir(int in)
{
  dir = in;
}

encoder encoder1(0), encoder2(1),encoder3(2);


void PrintData()
{
  Serial.print("e1:  ");
  Serial.print(encoder1.AngleRaw);
  Serial.print("  ");
  Serial.print("e2:  ");
  Serial.print(encoder2.AngleRaw);
  Serial.print("  ");
  Serial.print("e3:  ");
  Serial.println(encoder3.AngleRaw);
}

void setup()
{
  Serial.begin(9600);
  serial1.begin(9600);
  //Serial.println("testori");
  device1.init();

  /*encoder1.SetOffset(0);
  encoder1.SetDir(1);
  encoder2.SetOffset(0);
  encoder2.SetDir(1);
  encoder3.SetOffset(0);
  encoder3.SetDir(1);*/
}

void data_sender()//sent encoder value to master device
{
  char buf[receive_pack_len];

  if (Serial.availableForWrite())
  {
    /*Serial.write('a');
    dtostrf(encoder1.AngleRaw, 3, 1, buf);
    Serial.write(buf, receive_pack_len);
    Serial.write('b');
    dtostrf(encoder2.AngleRaw, 3, 1, buf);
    Serial.write(buf, receive_pack_len);
    Serial.write('c');
    dtostrf(encoder3.AngleRaw, 3, 1, buf);
    Serial.write(buf, receive_pack_len);*/
    Serial.print("a");
    float sent_temp;
    if(encoder1.AngleRaw<100){
      sent_temp=encoder1.AngleRaw+500;
    }
    else{
      sent_temp=encoder1.AngleRaw;
    }
    Serial.print(int(sent_temp));
    Serial.print("b");
    Serial.print(int(encoder2.AngleRaw));
    Serial.print("c");
    Serial.print(int(encoder2.AngleRaw)+int(encoder3.AngleRaw)-289);
    int checksum=int((int(encoder1.AngleRaw)+int(encoder2.AngleRaw)+int(encoder2.AngleRaw)+int(encoder3.AngleRaw)-289)/10)+100;
    Serial.print("d");
    Serial.println(checksum);
  }
}

void data_receiver()
{
  if(Serial.available())
  {
    serial1.println(Serial.read());
  }
}
/*void data_receiver()

  char pack_temp[receive_pack_len];
  double value_temp;
  if (Serial.available())
  {
    Serial.find('h');
    Serial.readBytes(pack_temp, receive_pack_len);
    value_temp = strtod(pack_temp, NULL);
    pid_hip.target = value_temp;

    Serial.find('k');
    Serial.readBytes(pack_temp, receive_pack_len);
    value_temp = strtod(pack_temp, NULL);
    pid_knee.target = value_temp;

    Serial.find('a');
    Serial.readBytes(pack_temp, receive_pack_len);
    value_temp = strtod(pack_temp, NULL);
    pid_ab.target = value_temp;
  }
}*/


void loop()
{
  encoder1.GetAngleraw();
  encoder2.GetAngleraw();
  encoder3.GetAngleraw();

  //Serial.println("test");
  //PrintData();
  data_sender();
  //data_receiver();
  delay(5);
}

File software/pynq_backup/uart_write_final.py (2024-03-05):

# coding: utf-8

# In[18]:


from pynq.overlays.base import BaseOverlay
from pynq.lib import MicroblazeLibrary
base = BaseOverlay('base.bit')
print('finish')

lib = MicroblazeLibrary(base.RPI, ['uart'])
uart_device = lib.uart_open(14,15)

list2 = [69,71]
while True:
    lib.uart_write(uart_device,list2, len(list2))

print("finish reading")


# In[45]:


from pynq.overlays.base import BaseOverlay
from pynq.lib import MicroblazeLibrary
base = BaseOverlay('base.bit')
print('finish')

lib = MicroblazeLibrary(base.RPI, ['uart'])
uart_device = lib.uart_open(14,15)# normal uart speed 9600

def in_range(ascii_in):
    if(ascii_in>=48 and ascii_in<=57):
        return 1
    else:
        return 0
    pass


def read_to_float(list_read):
    result=0
    ten_num=0
    for item in list_read:
        if(item!=46):
            ten_num+=1
        else:
            break
        pass
    
    for s in range(0,len(list_read)-1):
        if(s<=ten_num-1 and in_range(list_read[s])):
            result=result+(list_read[s]-48)*10**(ten_num-s-1)
            pass
        if(s==ten_num):#46,
            pass
        if(s>=ten_num+1 and in_range(list_read[s])):
            result=result+(list_read[s]-48)*10**(ten_num-s)
            pass
    return result
    pass



def get_device_angle(angle_read):
    temp=[0]
    temp1=[0,0,0,0,0,0]
    #angle_read=[0,0,0]

    lib.uart_read(uart_device,temp, 1)
    if(temp[0]==100):#selation d
        lib.uart_read(uart_device,temp1,6)
        temp_fl=read_to_float(temp1)
        if(temp_fl<360 and temp_fl>0):
            angle_read[0]=temp_fl#git rid of unneeded part
        pass
    if(temp[0]==97):#selation a
        lib.uart_read(uart_device,temp1,6)
        temp_fl=read_to_float(temp1)
        if(temp_fl<360 and temp_fl>0):
            angle_read[0]=temp_fl
        #print("a",angle_read[0])
        #print(temp1)
        pass
    if(temp[0]==98):#seaction b
        lib.uart_read(uart_device,temp1,6)
        temp_fl=read_to_float(temp1)
        if(temp_fl<360 and temp_fl>0):
            angle_read[1]=temp_fl
        #print("b",angle_read[1])
        #print(temp1)
        pass
    if(temp[0]==99):#seaction c
        lib.uart_read(uart_device,temp1,6)
        temp_fl=read_to_float(temp1)
        if(temp_fl<360 and temp_fl>0):
            angle_read[2]=temp_fl
        #print("c",angle_read[2])
        #print(temp1)
        pass
    return angle_read

angle_read=[0,0,0]
while True:
    angle_read=get_device_angle(angle_read);
    device_angle_raw=[angle_read[0]-116.1,257.7-angle_read[1],-61.5-(angle_read[1]-angle_read[2])]
    #print(device_angle_raw)
    

print("finish reading")


# In[ ]:


from pynq.overlays.base import BaseOverlay
from pynq.lib import MicroblazeLibrary
base = BaseOverlay('base.bit')
print('finish')

lib = MicroblazeLibrary(base.RPI, ['uart'])
uart_device = lib.uart_open(14,15)# normal uart speed 9600

def in_range(ascii_in):
    if(ascii_in>=48 and ascii_in<=57):
        return 1
    else:
        return 0
    pass


def read_to_float(list_read):
    result=0
    ten_num=0
    for item in list_read:
        if(item!=46):
            ten_num+=1
        else:
            break
        pass
    
    for s in range(0,len(list_read)-1):
        if(s<=ten_num-1 and in_range(list_read[s])):
            result=result+(list_read[s]-48)*10**(ten_num-s-1)
            pass
        if(s==ten_num):#46,
            pass
        if(s>=ten_num+1 and in_range(list_read[s])):
            result=result+(list_read[s]-48)*10**(ten_num-s)
            pass
    return result
    pass


def get_device_angle(angle_read):
    temp=[0]
    temp1=[]
    read_done=[0,0,0]
    #angle_read=[0,0,0]
    
    while(read_done[0]==0 or read_done[1]==0 or read_done[2]==0):
        
        lib.uart_read(uart_device,temp, 1)
        
        if(temp[0]==97):#selation a
            #print("a")
            count=0
            while(count<6):
                single=[0]
                lib.uart_read(uart_device,single, 1)
                if(temp!=0):
                    temp1.append(single[0])
                    count+=1
                    pass
                pass
            print(temp1)
            angle_1=read_to_float(temp1)
            if(angle_1<500):
                angle_read[0]=angle_1
            else:
                angle_read[0]=angle_1-500
            temp1=[]
            read_done[0]=1
            pass
    
        if(temp[0]==97):#selation b
            #print("b")
            count=0
            while(count<6):
                single=[0]
                lib.uart_read(uart_device,single, 1)
                if(temp!=0):
                    temp1.append(single[0])
                    count+=1
                    pass
                pass
            print(temp1)
            angle_read[1]=read_to_float(temp1)
            temp1=[]
            read_done[1]=1
            pass
    
        if(temp[0]==99):#selation c
            #print("c")
            count=0
            while(count<6):
                single=[0]
                lib.uart_read(uart_device,single, 1)
                if(temp!=0):
                    temp1.append(single[0])
                    count+=1
                    pass
                pass
            print(temp1)
            angle_read[2]=read_to_float(temp1)
            temp1=[]
            read_done[2]=1
            pass     

    return angle_read

angle_read=[0,0,0]
while True:
    angle_read=get_device_angle(angle_read);
    device_angle_raw=[angle_read[0]-116.1,257.7-angle_read[1],-61.5-(angle_read[1]-angle_read[2])]
    print(device_angle_raw)
    

print("finish reading")
    

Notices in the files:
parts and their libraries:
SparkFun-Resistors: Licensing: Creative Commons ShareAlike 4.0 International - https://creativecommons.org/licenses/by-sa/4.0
